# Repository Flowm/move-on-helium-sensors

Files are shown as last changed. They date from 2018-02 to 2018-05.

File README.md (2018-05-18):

# MOVE-ON Helium Sensors
Sensors subsystem for the MOVE-ON Helium high-altitude balloon mission.

A detailed system description can be found in the system documentation.

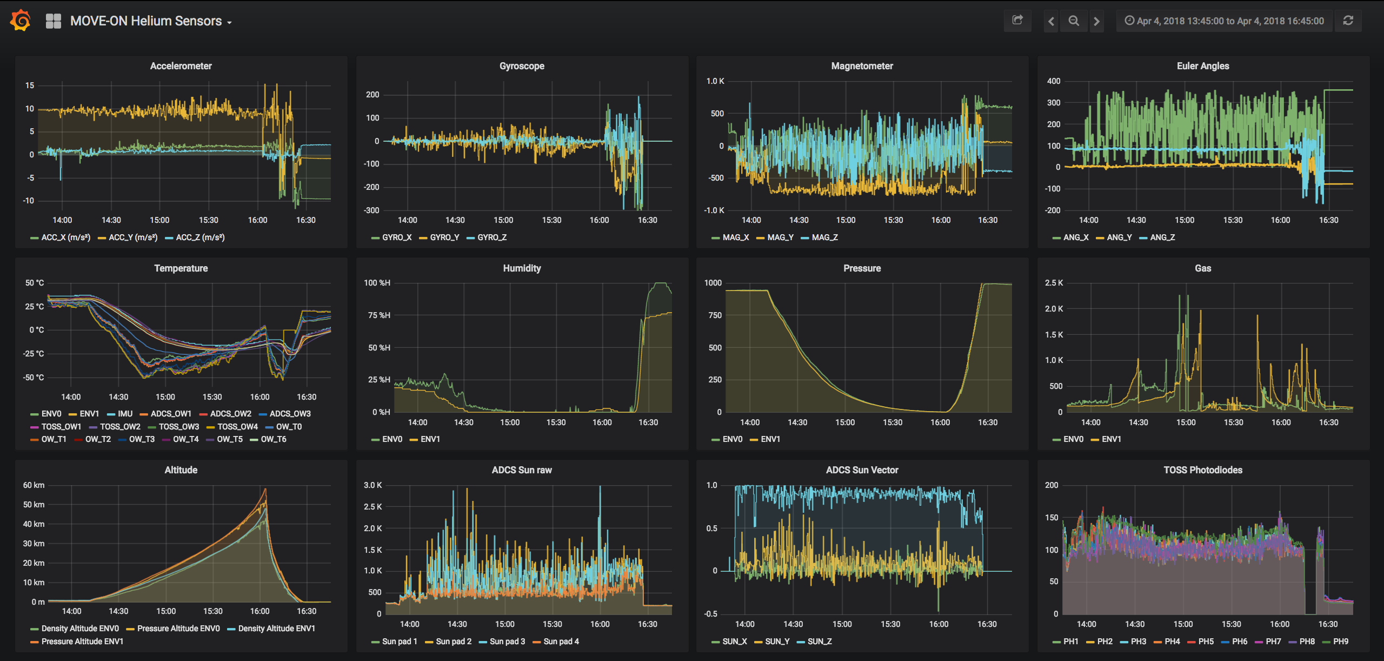
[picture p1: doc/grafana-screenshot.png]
Grafana dashboard


## Interfaces
### Micro USB
The output from Micro USB can be read with the following command (MacOS):
```
picocom -b 115200 /dev/tty.usbmodem1453
```
(`usbmodem1453` needs to be adjusted on your system)

## Setup
### Requirements
- GNU Arm Embedded Toolchain
- mbed-cli
- stlink

### MacOS
```
brew cask install gcc-arm-embedded
brew install stlink openocd direnv
sudo easy_install pip
pip install virtualenv

echo 'eval "$(direnv hook bash)"' >> ~/.bashrc
echo 'eval "$(direnv hook zsh)"' >> ~/.zshrc
```

If `pip install` does not work try it with the parameter `--user python`.

### Linux
```
sudo apt install gcc-arm-none-eabi openocd
sudo apt install python-pip python-dev build-essential direnv
pip install virtualenv

echo 'eval "$(direnv hook bash)"' >> ~/.bashrc
echo 'eval "$(direnv hook zsh)"' >> ~/.zshrc
```

### Mbed-cli
New shell in project directory:
```
direnv allow
pip install mbed-cli
```

## Development
### Compile
In `src` dir:
```
make
```

### Developing in SW4STM32 (Eclipse)
1. `mbed-cli export -i sw4stm32 --profile config/develop.json`
2. `File` -> `Open Projects from File System` (In Eclipse)
3. Choose the `move-on-helium-sensors` project.
4. Remember to regenerate the project files everytime you add a new library with `mbed-cli add ...`.

## Reference
### Build targets
From the `src` directory:

| Command | Description |
| --- | --- |
| make build (default) | Generate toplevel makefile and build project sources |
| make clean | Remove build artifacts and toplevel makefile |
| make flash | Upload firmware to locally attached uC with st-flash |
| make rflash | Upload firmware to uC attached to remote ci host |
| make rtail | Tail serial output from uC attached to remote ci host |
| make deploy | Combines rflash and rtail |

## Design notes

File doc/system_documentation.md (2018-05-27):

# MOVE-ON Helium Sensors System Documentation

This report documents the sensors subsystem of the MOVE-ON Helium mission.

Members of the Sensor team are:

* Florian Mauracher (<florian.mauracher@tum.de>)
* Tejas Kale (<tejas.kale@tum.de>)
* Alexander Lill (<alexander.lill@tum.de>)

## Resources & TL;DR

* [Repository](https://gitlab.lrz.de/move-on/move-on_helium_sensors)
* [System Architecture](https://gitlab.lrz.de/move-on/move-on_helium_sensors/blob/master/doc/system-architecture.png)
* [Nucleo Firmware](https://gitlab.lrz.de/move-on/move-on_helium_sensors/tree/master/src)
* [Hardware Schematics](https://gitlab.lrz.de/move-on/move-on_helium_sensors/tree/master/hardware)
* [Live data visualization](https://move.frcy.org)

## Mission Overview (MOVEON-GENERAL)

The MOVE-ON project aims to develop and start a high altitude pseudo satellite (HAPS) on board of a high-altitude (stratospheric) balloon every half year. This serves as a platform for short-lived and cost-efficient experiments to verify and test spacecraft technologies.

The expected mission duration for a high altitude balloon flight is 4 to 6 hours during which the balloon reaches an altitude up to 35 km.

The project is carried out by students of the [WARR](https://www.warr.de/en) (Scientific Workgroup for Rocketry and Spaceflight - German: Wissenschaftliche Arbeitsgemeinschaft für Raketentechnik und Raumfahrt in cooperation with the [LRT](https://www.lrt.mw.tum.de) (Chair of Astronautics) of the Technical University of Munich.

Suitable scientific or technical payloads are developed by students, employees of the LRT or provided by external partners and are the main driver for the technical requirements of every balloon mission.

MOVE-ON leverages existing knowledge from previous satellite missions of the chair and prepares the team as well as new technologies for upcoming satellite generations.

### Strategic Mission Goals (MOVEON-GENERAL)

MOVE-ON is the follow-up mission of the [MOVE-II](https://www.move2space.de/MOVE-II) miniature satellite (CubeSat) that was developed by the LRT together with students of the WARR.

The MOVE-ON missions are intended as a transitional project until the next satellite mission and aim to pass existing knowledge of the development of small satellites to a new generation of students and deepen their understanding of related technologies.

Besides distributing in-depth technical knowledge it also focuses on the upkeep and improvement of established processes and tools in regards to hardware and software.
Leveraging the relatively short and repeated development cycles (in comparison to small satellites) it additionally aims to create an adapted strategy for the agile development of embedded systems on small satellites.

### Technical Goals (MOVEON-GENERAL)

Existing technologies of previous and current satellite missions are intended to be used, extended and tested whenever possible.
Additionally, the continuous in-house development of the central subsystems for small satellites improves the capabilities of the LRT and the WARR in the development, manufacturing and qualification of satellite technology.
New strategies for the design and development of embedded systems can be tested rapidly with minimal cost and small associated risks.

## MOVE-ON Helium System Overview (MOVEON-HE-GENERAL)

The MOVE-ON Helium mission consists of a balloon, connecting strings and a gondola with a payload mounted on top of the gondola. The gondola is a PVC box and consists of all the mission-critical components including power, communication and health monitoring systems. The box serves to insulate the electronics from the extremely cold temperatures in the stratosphere.

The system is split into several key subsystems. Such a modular architecture allows for a structured development approach where each subsystem is developed and tested independently.



 The MOVE-ON Helium balloon has the following subsystems interconnected as shown in the figure above:

Command and Data Handling (CDH)
:   The CDH subsystem is the brain of the gondola. It controls all the other subsystems via various interfaces. CDH controls the power to the various systems and can switch off noncritical systems when the batteries run low or a subsystem is malfunctioning. Data from the sensors system is used for monitoring the health of the gondola and also its GPS position. CDH downlinks this telemetry data via the COM subsystem to the ground station.

Sensors (SEN)
:    The sensors subsystem provides environmental data and system health information for monitoring and tracking the balloon. It houses various sensors including a GPS module which provides the real-time position of the balloon.

Electrical Power System (EPS)
:   EPS houses the batteries, solar cells and the voltage converters. It is responsible for providing power to all the other subsystems. The EPS is designed in a modular way such that multiple such systems can be plugged in to scale to the needs of the mission. [ref: Thomas Grübler (12.2017) "Highly Integrated Smart Satellite Panels for Commercial Space Applications"]

Communications (COM)
:   The COM system consists of an RF link and is responsible for sending telemetry data from the balloon to the ground station.

Camera (CAM)
:   The camera system houses a GoPro capturing cool photos from the edge of space.

Payload (PL)
:   Payload is the scientific payload that is the main purpose of this balloon mission. It is mounted on top of the gondola and sends its data to CDH for transmission to the ground station.

Over the past 2 months, we have worked on developing the Sensors subsystem, starting from selecting commercially available components to integrating all of them on a single PCB. This subsystem is described in detail in the next section.

## System Description

The main responsibility of the sensors subsystem is to collect data from all connected sensors and provide this data to the CDH subsystem upon request. Simultaneously the collected data is stored locally at a higher data rate for later analysis.

Key components of the sensors subsystem

The sensors subsystem consists of the following key components:
<!--The figure below shows the key components of the subsystem and the connections between them.-->

* Internal Board
  * Microcontroller (NUCLEO-L432KC)
  * Storage Module (Adafruit OpenLog)
  * GPS module (uBLOX MAX-M8C Pico)
  * Motion sensor (BNO055)
* External Boards
  * Environmental sensor (BME680)
  * Sun Sensor (MOVE-II ADCS Sidepanel)
  * Sun Sensor (TOSS Photodiode board)
* Distributed on Gondola
  * 4x Temperature sensors (DS18B20)

The internal board is a self-developed PCB which is mounted on the inside of the gondola. The external boards were mounted as described in the Structure chapter. They are connected over SPI to the microcontroller. Multiple temperature sensors are placed near critical components of the gondola and also on the outside of the gondola.

During testing, it was found that the GPS does not work when wrapped with MLI. Due to this, the GPS module was mounted on a side wall with its antenna sticking out of the MLI insulation.
<!--
Each component is connected to the microcontroller using one of the  following communication buses, depending on what the sensor supports:
* UART
* I^2^C
* SPI
* OneWire-->

### Hardware

Since this is a proof of concept mission for the new sensors microcontroller, breakout boards are used for the majority of components. This enables fast prototyping and easy development.

For the initial verification of all components and connections the breakout boards were combined on a single breadboard as visible on the image below.


After successful verification, a PCB was designed integrating all internal breakout boards and providing dedicated connectors for each external component. The hardware schematics are available in the [repository](https://gitlab.lrz.de/move-on/move-on_helium_sensors/tree/master/hardware).



In the future all of the internal sensors could be integrated onto a single PCB which would significantly decrease the physical dimensions and weight of the board.

#### Microcontroller (NUCLEO-L432KC)

Our main computing module is a NUCLEO-L432KC development board with the following features:

* STMicroelectronics STM32L432KC microcontroller in 32-pin package
* ARM Cortex M4 architecture with FPU
* Adjustable CPU frequency from 2-80 Mhz
* 256 KB Flash and 64 KB SRAM
* Support for the ARM mbed OS Real-time operating system (RTOS)
* On-board ST-LINK/V2-1 debugger/programmer

The ARM Cortex-M4 based microcontroller was chosen due to its low base power consumption with reduced clock frequency while still offering sufficient processing power for higher level abstractions and possible future data processing.

### Software

#### Operating System

The MOVE-ON Sensor board is using the ARM Mbed OS real-time operating system. Mbed OS provides a convenient abstraction for the complexity of the underlying ARM Cortex-M4 microcontroller.

The RTOS functionality of Mbed OS with its priority based scheduling allows event-based actions with a guaranteed response rate and multiple concurrent threads with different priorities.

#### Data Acquisition

<!--
```https://www.planttext.com/
@startuml

class Sensors {
  -BNO055IMU imu;
  -BME680 env0;
  -BME680 env1;
  -Sidepanel adcs;
  -DS18B20 temperature;
  -GPS gps;
  -Storage storage;
  -CDHUart cdhuart;
  +void setup();
  +void loop();
  +void log();
}

class SensorThread {
  +void start()
  +void loop()
  +bool setup()
  +void update()
  +void set_update_rate(int)
  +void set_priority(priority)
  -Thread _thread
}

class BNO055IMU
class BME680
class Sidepanel
class DS18B20
class GPS

SensorThread <|-down- BNO055IMU: Inheritance
SensorThread <|-down- BME680: Inheritance
SensorThread <|-down- Sidepanel: Inheritance
SensorThread <|-down- DS18B20: Inheritance
SensorThread <|-down- GPS: Inheritance

Sensors "1" -right- "*" SensorThread: "      "

@enduml
```
-->

```mermaid
sequenceDiagram
    participant m as main
    participant s as Storage
    participant c as CDHUart
    participant thread as SensorThread
    participant l as OpenLog
    participant cdh as CDH

    m->>+s: new()
    m->>+c: new()
    m->>+thread: start()

    loop Every second
        thread->>thread: update()
        thread->>s: lock()
        thread->>s: store_data()
        thread->>s: unlock()
    end

    loop Every second
        m->>s: lock()
        m->>s: retrieve_data()
        s-->>m: data
        m->>s: unlock()
        m->>l: print()
    end

    opt sometimes
        cdh->>c: request_data()
        c->>s: lock()
        c->>s: retrieve_data()
        s-->>c: data
        c->>s: unlock()
        c->>cdh: data
    end

    thread-->>-m:terminate()
```

To gather the data from multiple different sensors, each sensor is implemented as a self-contained module in the form of a separate class with all its dependencies.
Each sensor module is running as a separate thread with a set refresh rate, relying on Mbed OS for scheduling between the threads.

Each sensor thread communicates with its respective sensor to initiate a measurement when required and gather the resulting data.The data is then stored in a shared data structure containing the latest measurements from each sensor. To ensure the data structure remains consistent at all times a mutex is used to lock the data structure immediately before storing the data and unlock it again right afterwards.

At the end of a measurement period each sensor thread sleeps for the remaining time until the desired data update rate is reached, providing sufficient time for all other sensor threads to be scheduled.

#### Sensor Update Frequency

| Sensor | Update Frequency(ms) |
| --- | ---: |
| GPS | 1000 |
| BME | 1000 |
| BNO055-IMU | 200 |
| SidePanel | 200 |
| TOSS | 500 |
| One Wire Temp | 2000 |

#### CDH Communication

CDH asks the sensors system for data every second over the UART link by sending a single command byte. The response is a mutually agreed upon data structure which contains the most recent sensor data. The content is verified with a CRC checksum to avoid data corruption.

As GPS data is critical for real-time balloon tracking and time synchronization, responding to CDH data requests is handled with a high priority event queue. When a new request for data comes in from CDH (a byte is received on the UART RX line), an interrupt is generated by the UART peripheral on the microcontroller. The interrupt handler simply reads the command and queues an event onto the event queue for processing. The event callback is then executed when the responsible thread gets scheduled the next time. The command processor then responds with the sensor data on the UART TX line.

#### Persistent Data Storage

A UART data logger module is used to log data locally on the sensors subsystem. This is required because:

* CDH cannot handle data at high frequency due to power budget constraints
* Different sensors produce different amounts of data at different rates
* In case of a CDH failure, we will still have a backup of the sensor data

This is implemented using the OpenLog module from [Sparkfun](https://www.sparkfun.com/products/13712). It is an Atmel Xmega 328p microcontroller which logs all data that it receives via UART to an SD card. The used SD card has a capacity of 32 GB and provides sufficient storage capacity for up to a month of continuous data storage ( `115200/8*60*60*24/1024/1024/1024` = 1.15 GB/day with 100% utilization of the UART line).

### Sensors

The following sensor modules are integrated into the sensors subsystem.

#### GPS Module (uBLOX MAX-M8C Pico)

The MAX-8 series of standard precision GNSS modules features the reliable performance of the u-blox 8 positioning engine, which receives GPS, GLONASS, QZSS and SBAS signals. The MAX-8 series delivers high sensitivity and minimal acquisition times in an ultra compact form factor. The MAX-8 series provides high sensitivity while featuring low power consumption. It also supports advanced Power Save Modes. It also provides message integrity protection, geofencing, spoofing detection, and odometer functionalities. The module also supports a high altitude mode which works up to 50 km in flight mode.

The module is connected to the microcontroller over a dedicated I^2^C bus. It provides GPS data in the standard NMEA format. This raw NMEA is parsed to extract the time and real-time GPS position. Since NMEA also consists of other useful data, it is also logged in raw form.

For configuration of the sensor module, the uBLOX supports a proprietary binary protocol. This protocol is currently neither used nor implemented, but instead configuration messages can be created using a software provided by uBLOX to generate these binary messages which can then be written to the module over I^2^C.

For the flight the GPS was configured with the following settings:

* Dynamic Model : Airborne 2g mode
* Min SV elevation : 0
* Fix Mode : 3D only

The software is configured to write the UBX CFG message to the GPS chip on startup. Further, the GPS module always transmits the last known location in case there is no GPS lock.

#### Motion Sensor (BNO055)

The Bosch Sensortec BNO055 motion sensor implements an intelligent 9-axis Absolute Orientation Sensor, which includes sensors and sensor fusion in a single package. This sensor integrates a triaxial 14-bit accelerometer, a triaxial 16-bit gyroscope with a maximum range of ±2000 degrees per second, a triaxial geomagnetic sensor and a 32-bit microcontroller running the company's BSX3.0 FusionLib software. The BNO055 is connected over a second I^2^C bus.

Attitude data from this sensor is used to measure the orientation of the gondola and also to test the effectiveness of a stabilization system developed by the structure team. This data is also used to mark the exact time when the balloon bursts and the gondola starts its free fall.

#### Environmental Sensor (BME680)

The Bosch Sensortec BME680 is described as an environmental sensor and provides, besides measurements of the temperature, humidity and pressure also an estimate of the current air quality in the form of a gas resistance measurement. The sensor provides an SPI interface for configuration and data retrieval.

Temperature and pressure data from this sensor is combined on the ground to provide an additional altitude calculation based on a simple [atmospheric density model](tools/grafana/bin/sensor-parser/moveon-sen-parser.cpp).

#### Sun Sensor (MOVE-II ADCS Sidepanel)

Sun angle sensors used in the MOVE-II CubeSat are commercial-off-the-shelf components, which are not extensively tested for space operation. The MOVE-ON mission provides an excellent platform for testing the performance of these sensors in a space-like environment. One of the side panels from the MOVE-II CubeSat is attached to the exterior of the gondola to record data from the sun sensor attached to it. This panel also has an IMU and various temperature sensors. Data from these is also recorded.

The Sidepanel is connected over the same SPI bus that connects all the external components of the sensor subsystem. It operates as a SPI slave and responds to data requests from the Nucleo microcontroller. The Sidepanel has the same software version as on the MOVE-II satellite.

#### Sun Sensor (SFH 2430)

A separate component with multiple photodiodes arranged in a spherical manner is being developed by students of the [*Practical Course on Astronautics*](https://www.lrt.mw.tum.de/index.php?id=172&L=1).

This experimental payload aims to provide a primitive sun sensor by combining the measurements of the photodiodes and some supplemental temperature sensors. An [Atmel AtMega32u4 breakout](https://www.dfrobot.com/product-1075.html) combines these measurements and provides a calculated sun vector as well as the raw data over a SPI interface to the Nucleo sensor board.

#### Temperature Sensors (DS18B20)

The DS18B20 digital thermometer provides 9-bit to 12-bit Celsius temperature measurements from -55°C to +125°C with a 0.5°C accuracy from -10°C to +85°C. This sensor communicates over a 1-Wire bus that by definition requires only one data line (and ground). In addition, the DS18B20 can derive power directly from the data line ("parasite power"), eliminating the need for an external power supply. The 1-Wire protocol required for interfacing with this sensor is implemented in software using an mbed library.

### Development Environment

While each team member has his own Nucleo board and the sensor he's currently working on, most sensors were only available twice during development. To allow regular testing of all components in a combined setup, we set up a continuous integration and deployment pipeline based on GitLab and the GitLab Runner.

After every commit the GitLab Runner starts the docker container with the mbed-cli development environment, compiles the project and gathers the resulting firmware as an artifact. The next stage of the pipeline then uses this firmware image to flash the Nucleo microcontroller with all sensors attached which is connected to a Raspberry PI reachable from the build server. Additionally, debug output is captured over the USB serial port and logged in the build log.

### Data Visualization

In testing configuration, the Raspberry Pi logs data on the USB debug line of the Nucleo board, which is used by the OpenLog in the flight configuration. This data is then parsed by a Python script, published over the messaging protocol MQTT and stored as time series in an InfluxDB database. The Grafana web frontend provides an interactive visualization of the stored data.

Grafana screenshot

InfluxDB supports multiple data sources and can easily be extended to accept data received over the COM link for live telemetry and tracking in flight.

### Power

Currently the sensors subsystem with all sensors connected consumes an average of 326 mW. Although there are no hard power requirements for the power budget of the sensors system energy consumption was kept in mind throughout the component selection and development process.

Nevertheless there are certain components that require significant amounts of energy impacting the total energy consumption:

|Component | Consumption | Disclaimer |
|- | - | - |
|uBlox GPS | <74 mW | During GPS acquisition|
| OpenLog | <70 mW | When writing to SD card flash |
|MOVE-II ADCS Sidepanel | ~60 mW | Separate XMega uC |
|TOSS Photodiode | ~50 mW  | Separate AVR uC |
|Microcontroller + Sensors | *~72mW* | *Approximate value, naively calculated* | <!-- 326-74-70-60-50 -->
|**Sum** | **326 mW** | |

## Flight

The sensors microcontroller gathered data continuously for the entire duration of the flight. It did not reset even at the low temperatures experienced during the transition through the upper parts of the troposphere. However not all sensors functioned correctly for the entire duration of the flight:

* GPS could not acquire a lock during most of the flight. This was most likely caused due to its close proximity to the MLI wrapping.
* The FAT32 filesystem on the SD card was corrupted sometime during the final integration. Due to this, no data was recorded on the OpenLog SD card during the flight.

### Flight Data

Flight data was recovered from the CDH SD card after the gondola was recovered. This data is presented below.

#### System Status

#### Temperature

The one wire temperature sensors were positioned on the gondola as follows:

| SENSOR | POSITION|
| --- | --- |
|OW0 |EPS Board|
|OW1 |U1 (Sensors Board)|
|OW2 |U3 (Sensors Board)|
|OW3 |Palyoad|
|OW4 |GoPro|
|OW5 |Battery Pack|
|OW6 |U2 (Sensors Board)|

Along with the 7 one wire temperature sensors of the sensors subsystem, the following other temperature sensors from other components were available:

* 3 One wire temperature sensors on the ADCS Sidepanel
* 4 One wire temperature sensors on the TOSS sunsensor board
* One temperature sensor integrated into each BME680 chip
* One temperature sensor on the BMX055 IMU.

The following graph presents the temperature profile of the flight as seen by the various sensors. A clear gap is seen in the internal and the external temperatures.

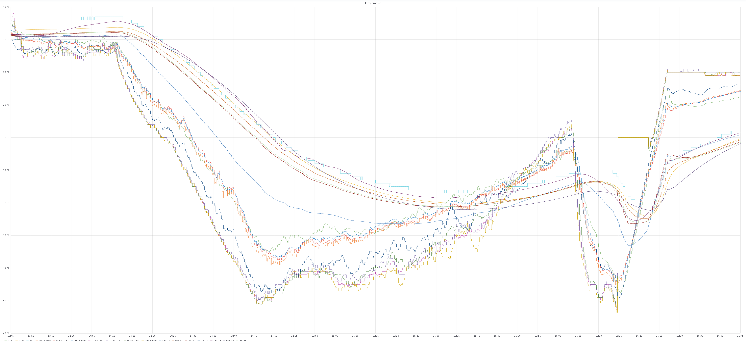
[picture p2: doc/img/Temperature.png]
Temperature profile


#### Pressure and Altitude

The following graph shows the pressure as recorded by the two BME680 sensors. The ENV0 sensor was placed outside while the ENV1 sensor was inside the gondola.

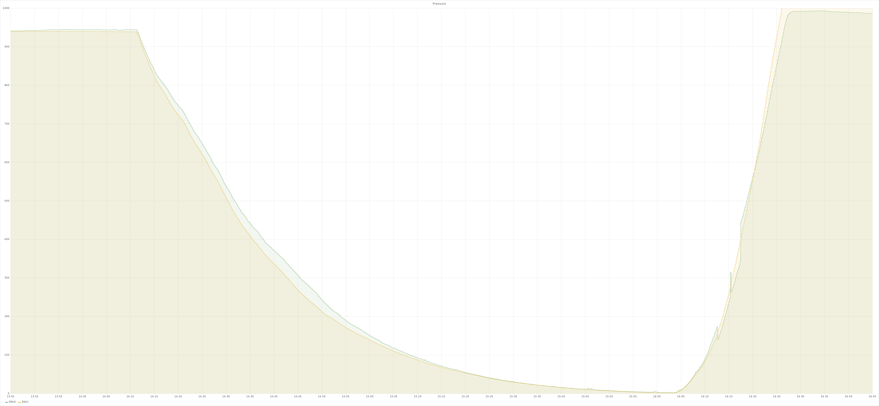
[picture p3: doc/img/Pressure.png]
Pressure profile


Altitude was calculated using two different methods:

1. [Pressure Altitude](https://en.wikipedia.org/wiki/Pressure_altitude) is calculated using only the pressure.
2. [Density Altitude](https://en.wikipedia.org/wiki/Density_altitude) is the Pressure altitude adjusted for temperature.

The following graph shows the altitude of the flight:
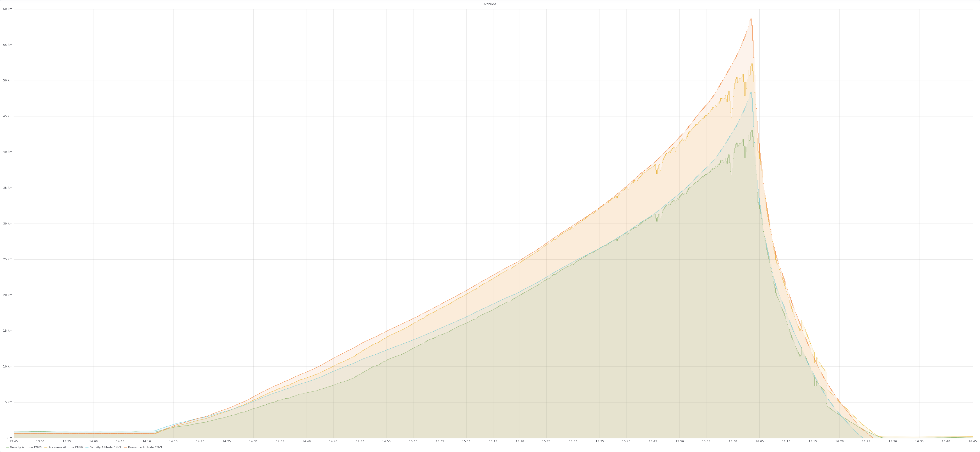
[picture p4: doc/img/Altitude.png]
Altitude profile


#### Motion Data

The BNO055 IMU recorded the gondola rotational speed, acceleration due to gravity, magnetic field data and the euler angles calculated onboard the sensor.

The following graphs show the gyroscope, Accelerometer and magnetometer data over the flight duration.

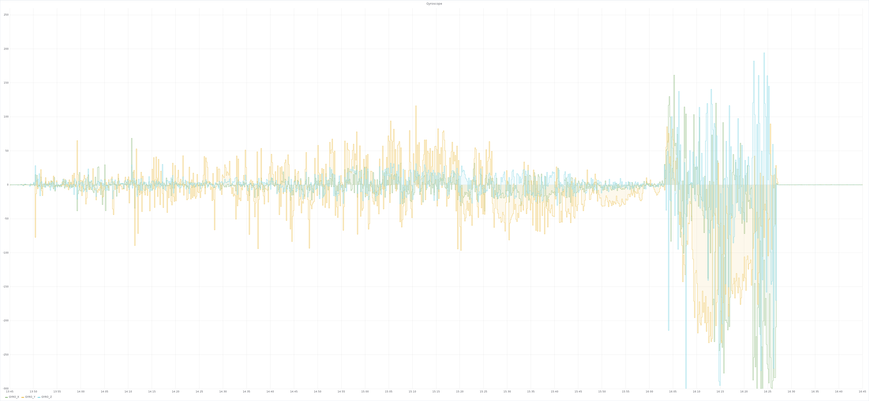
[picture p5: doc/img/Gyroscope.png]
Gyroscope profile

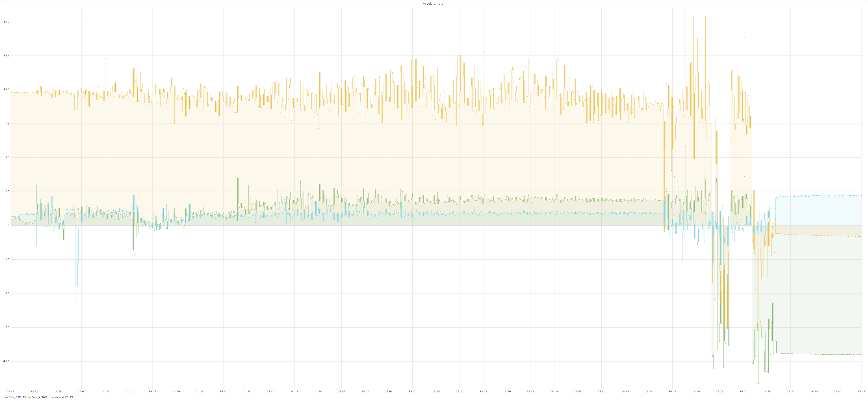
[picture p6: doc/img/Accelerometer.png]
Accelerometer profile

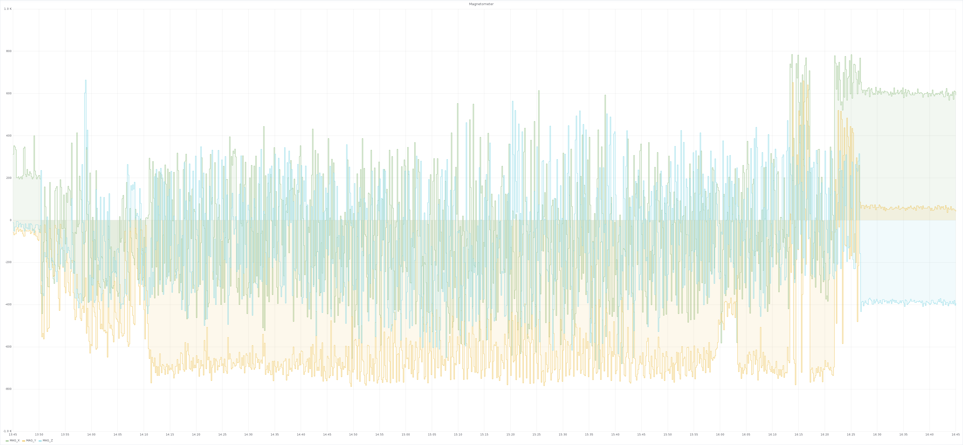
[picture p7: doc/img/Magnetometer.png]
Magnetometer profile


#### ADCS Sidepanel Data

The raw pad data from the ADCS sidepanel is shown below. The pads didnot exceed the ADC threshold of the sidepanel microcontroller.

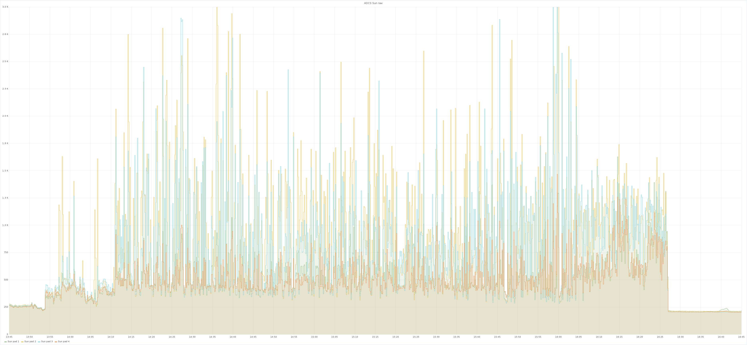
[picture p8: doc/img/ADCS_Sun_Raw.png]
Sun Raw profile


## References

### Sensor Modules

* [Components List](https://docs.google.com/spreadsheets/d/1G8NeRl4uM_pISfbMc-lu1pe1I8vzOqsSfUeEpfeaWEo/edit#gid=0)
* [GPS Ublox Max M8](https://store.uputronics.com/index.php?route=product/product&path=60_64&product_id=72)
* [BNO055 IMU](https://www.adafruit.com/product/2472)
* [BME680 Enviornment](http://www.watterott.com/en/BME680-Breakout)
* [DS18B20 Temperature](https://datasheets.maximintegrated.com/en/ds/DS18B20.pdf)
* [MOVE-II ADCS SidePanel](https://redmine.move2space.de/projects/move2/wiki/Sidepanel_401)
* [Open Log Datalogger](https://www.sparkfun.com/products/13712)

### Source Code

* [MOVE-ON Helium Sensors](https://gitlab.lrz.de/move-on/move-on_helium_sensors/)
* [MOVE-II ADCS](https://gitlab.lrz.de/move-ii/adcs_software)
* [TOSS Sunsensor](https://gitlab.lrz.de/racoon-projects/thermal-sun-sensor)

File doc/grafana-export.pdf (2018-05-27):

# MOVE-ON Helium Sensors

Postflight analysis of the data stored on the CDH SD card

## Wed Apr 4 11:45:00 UTC 2018

to

## Wed Apr 4 14:45:00 UTC 2018

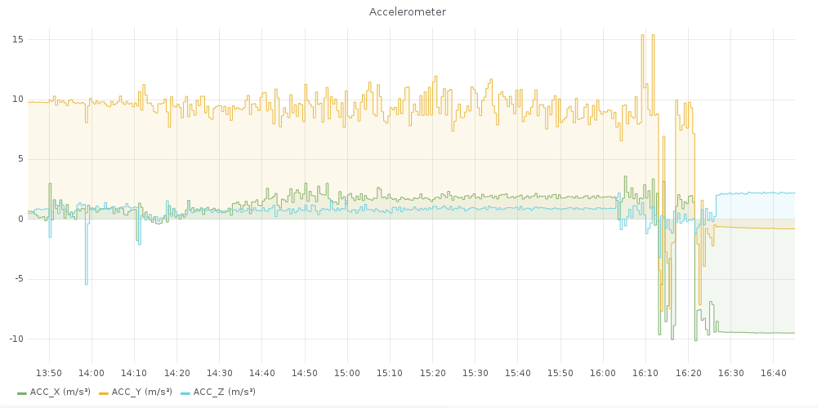
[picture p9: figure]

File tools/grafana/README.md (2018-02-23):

# Grafana visualization of moveon data

## Setup

### Components
- [Mosquitto](https://github.com/eclipse/mosquitto)
- [InfluxDB](https://github.com/influxdata/influxdb)
- [Telegraf](https://github.com/influxdata/telegraf)
- [Grafana](https://github.com/grafana/grafana)
- [Nginx](https://github.com/nginx/nginx)

### Install
- Automated setup of required software using [piot-ansible](https://github.com/Flowm/piot-ansible):
```
ansible-playbook -i "devpi," devpi.yml
```

- Clone the move-on_helium repository to `/opt/move-on_helium`
```
sudo mkdir -p /opt/move-on_helium
sudo chown deploy: /opt/move-on_helium
git clone --recurse-submodules git@gitlab.lrz.de:move-on/move-on_helium.git /opt/move-on_helium
```

- Install services and config
```
sudo /opt/move-on_helium/SEN/tools/grafana/setup.sh
```

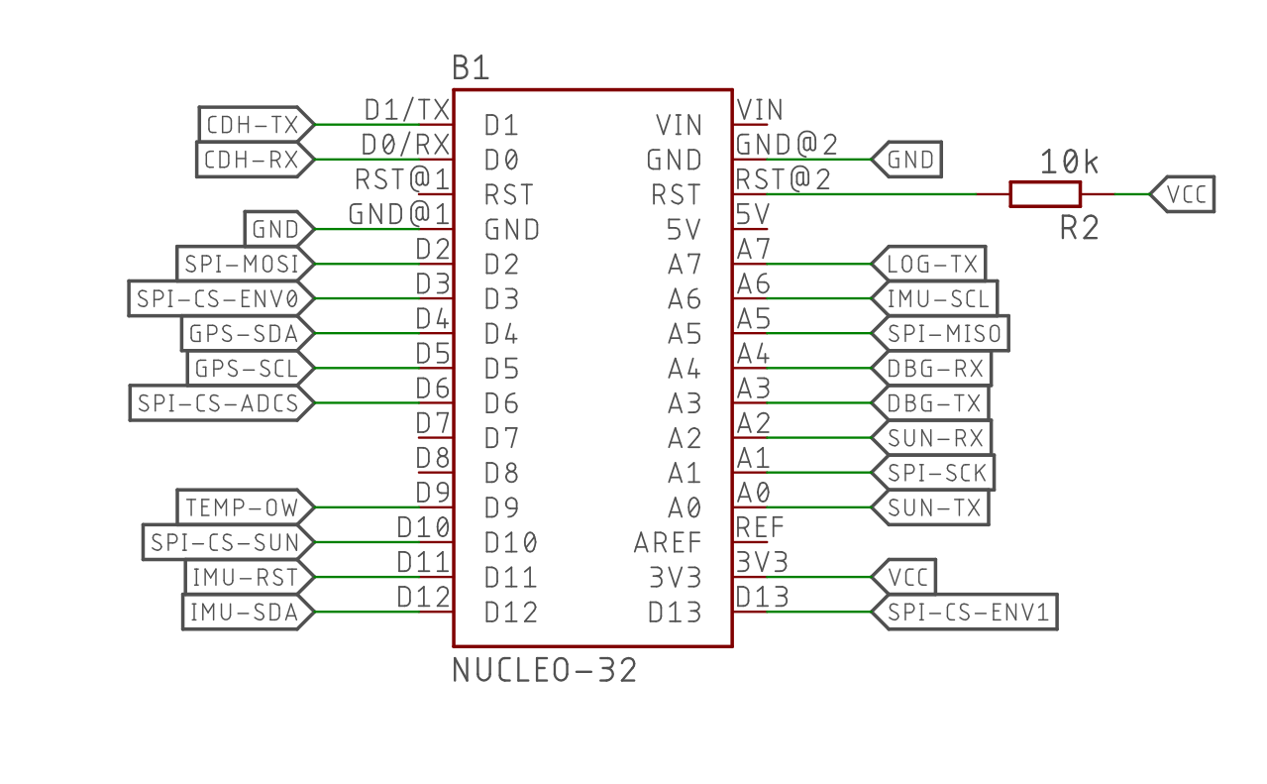
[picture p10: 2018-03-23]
doc/pinout.png

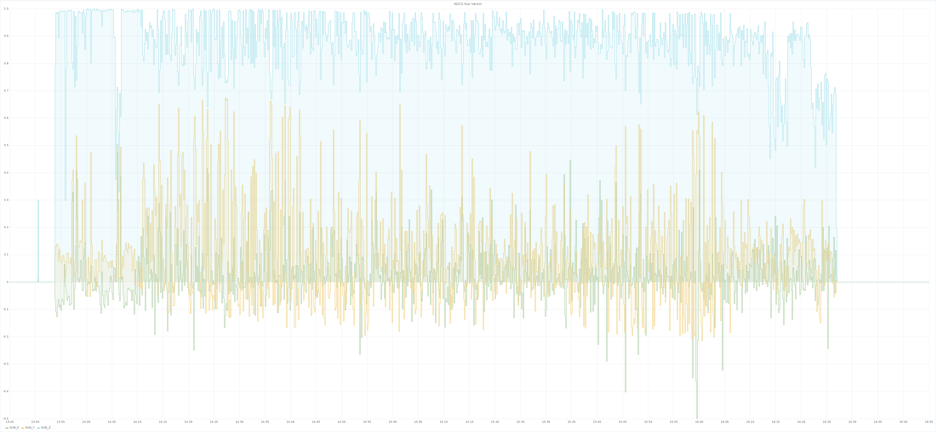
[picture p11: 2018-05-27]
doc/img/ADCS_Sun_Vector.png

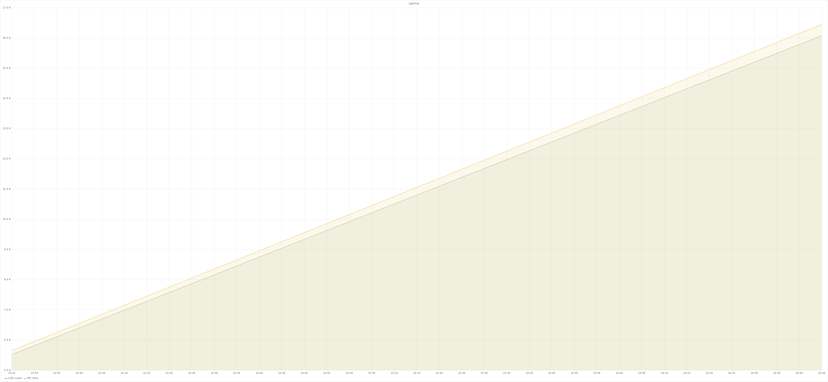
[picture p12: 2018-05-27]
doc/img/Uptime.png

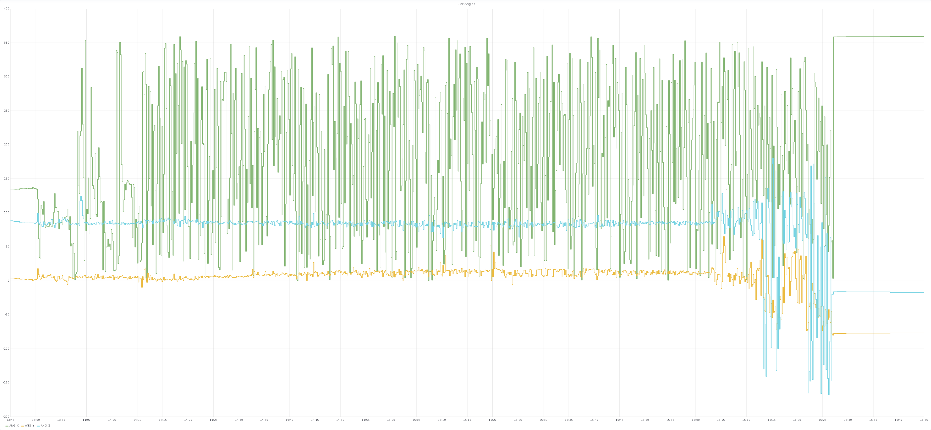
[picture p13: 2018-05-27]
doc/img/Euler_Angles.png

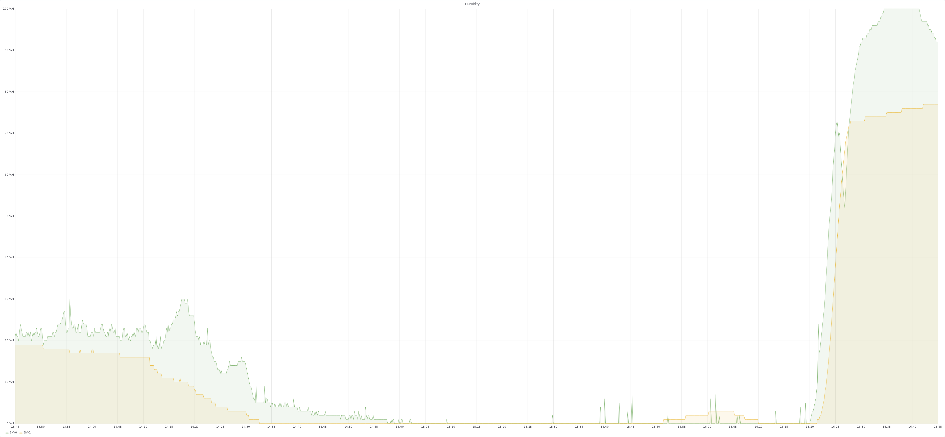
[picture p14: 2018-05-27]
doc/img/Humidity.png

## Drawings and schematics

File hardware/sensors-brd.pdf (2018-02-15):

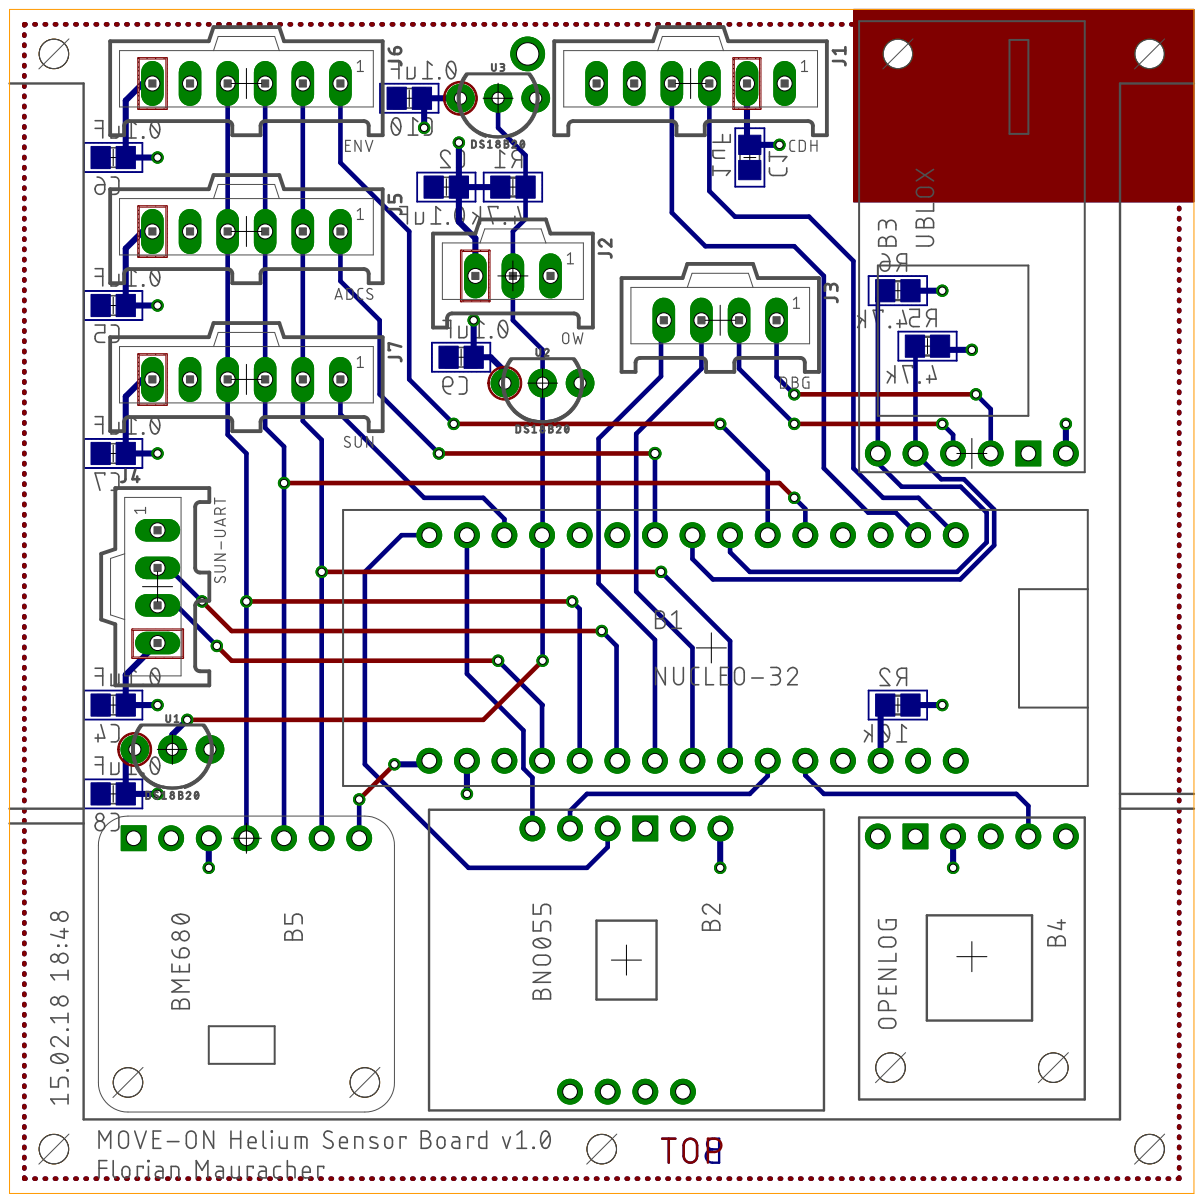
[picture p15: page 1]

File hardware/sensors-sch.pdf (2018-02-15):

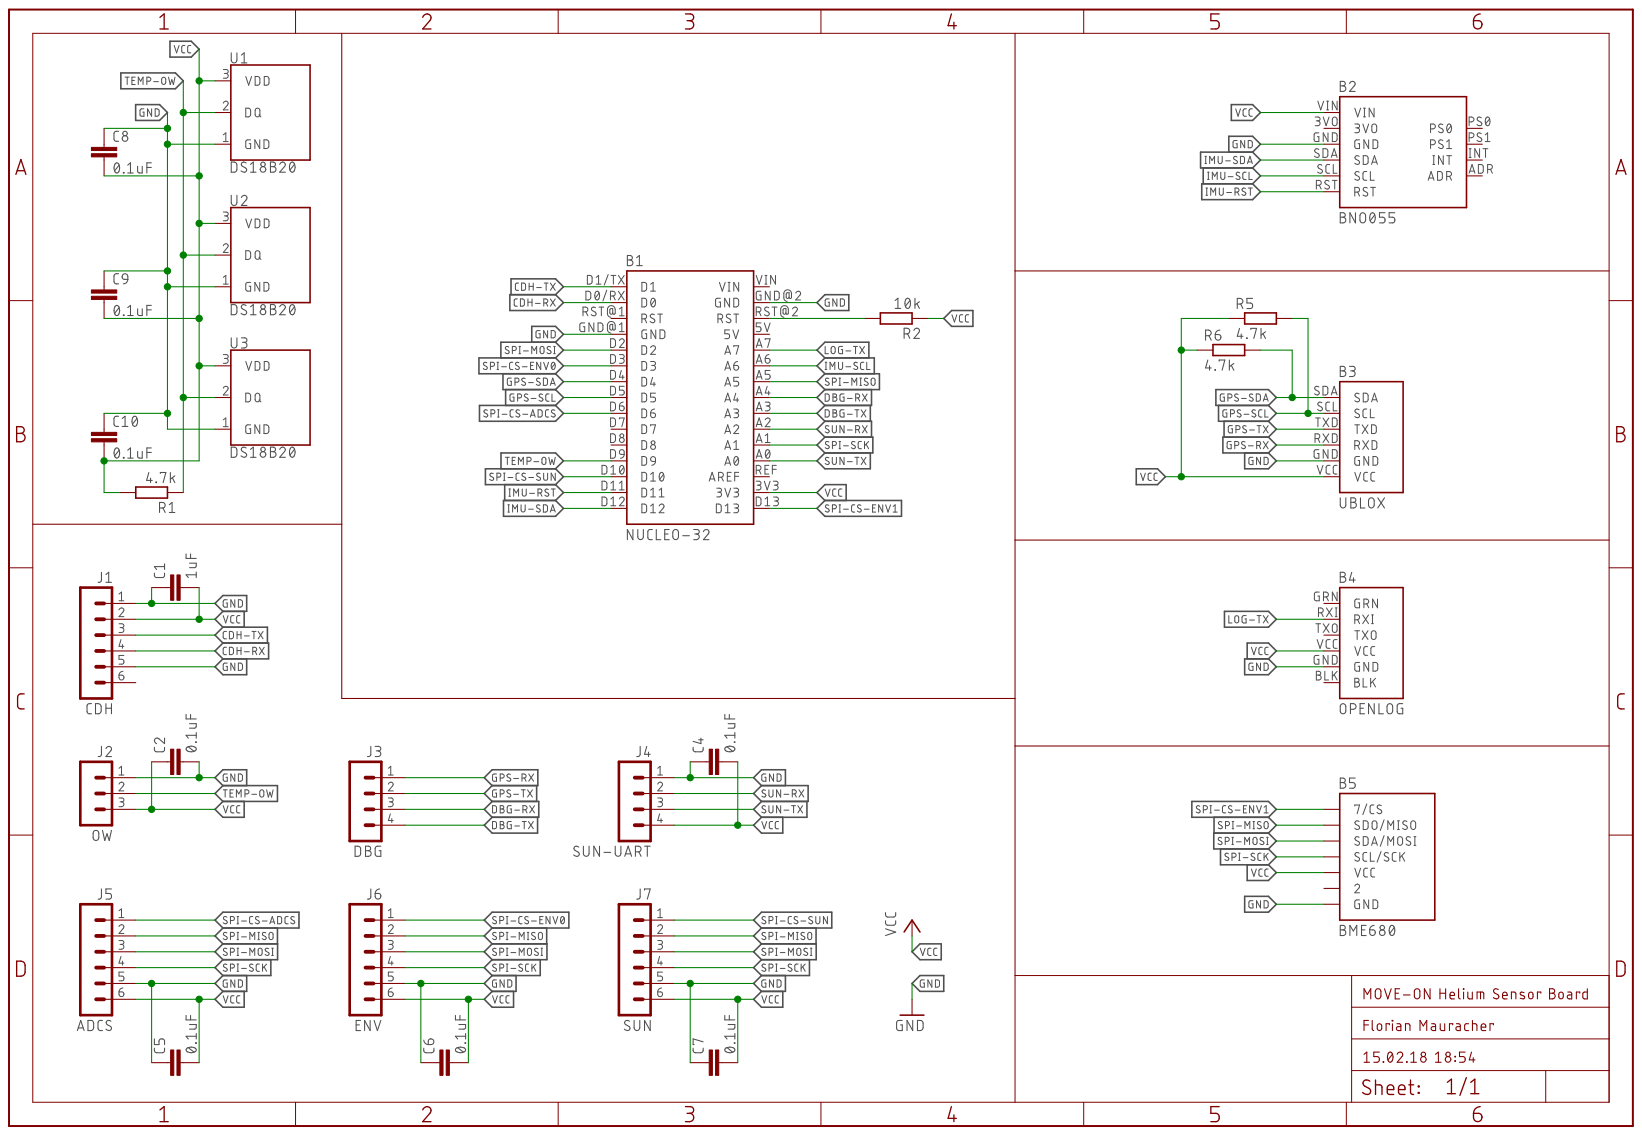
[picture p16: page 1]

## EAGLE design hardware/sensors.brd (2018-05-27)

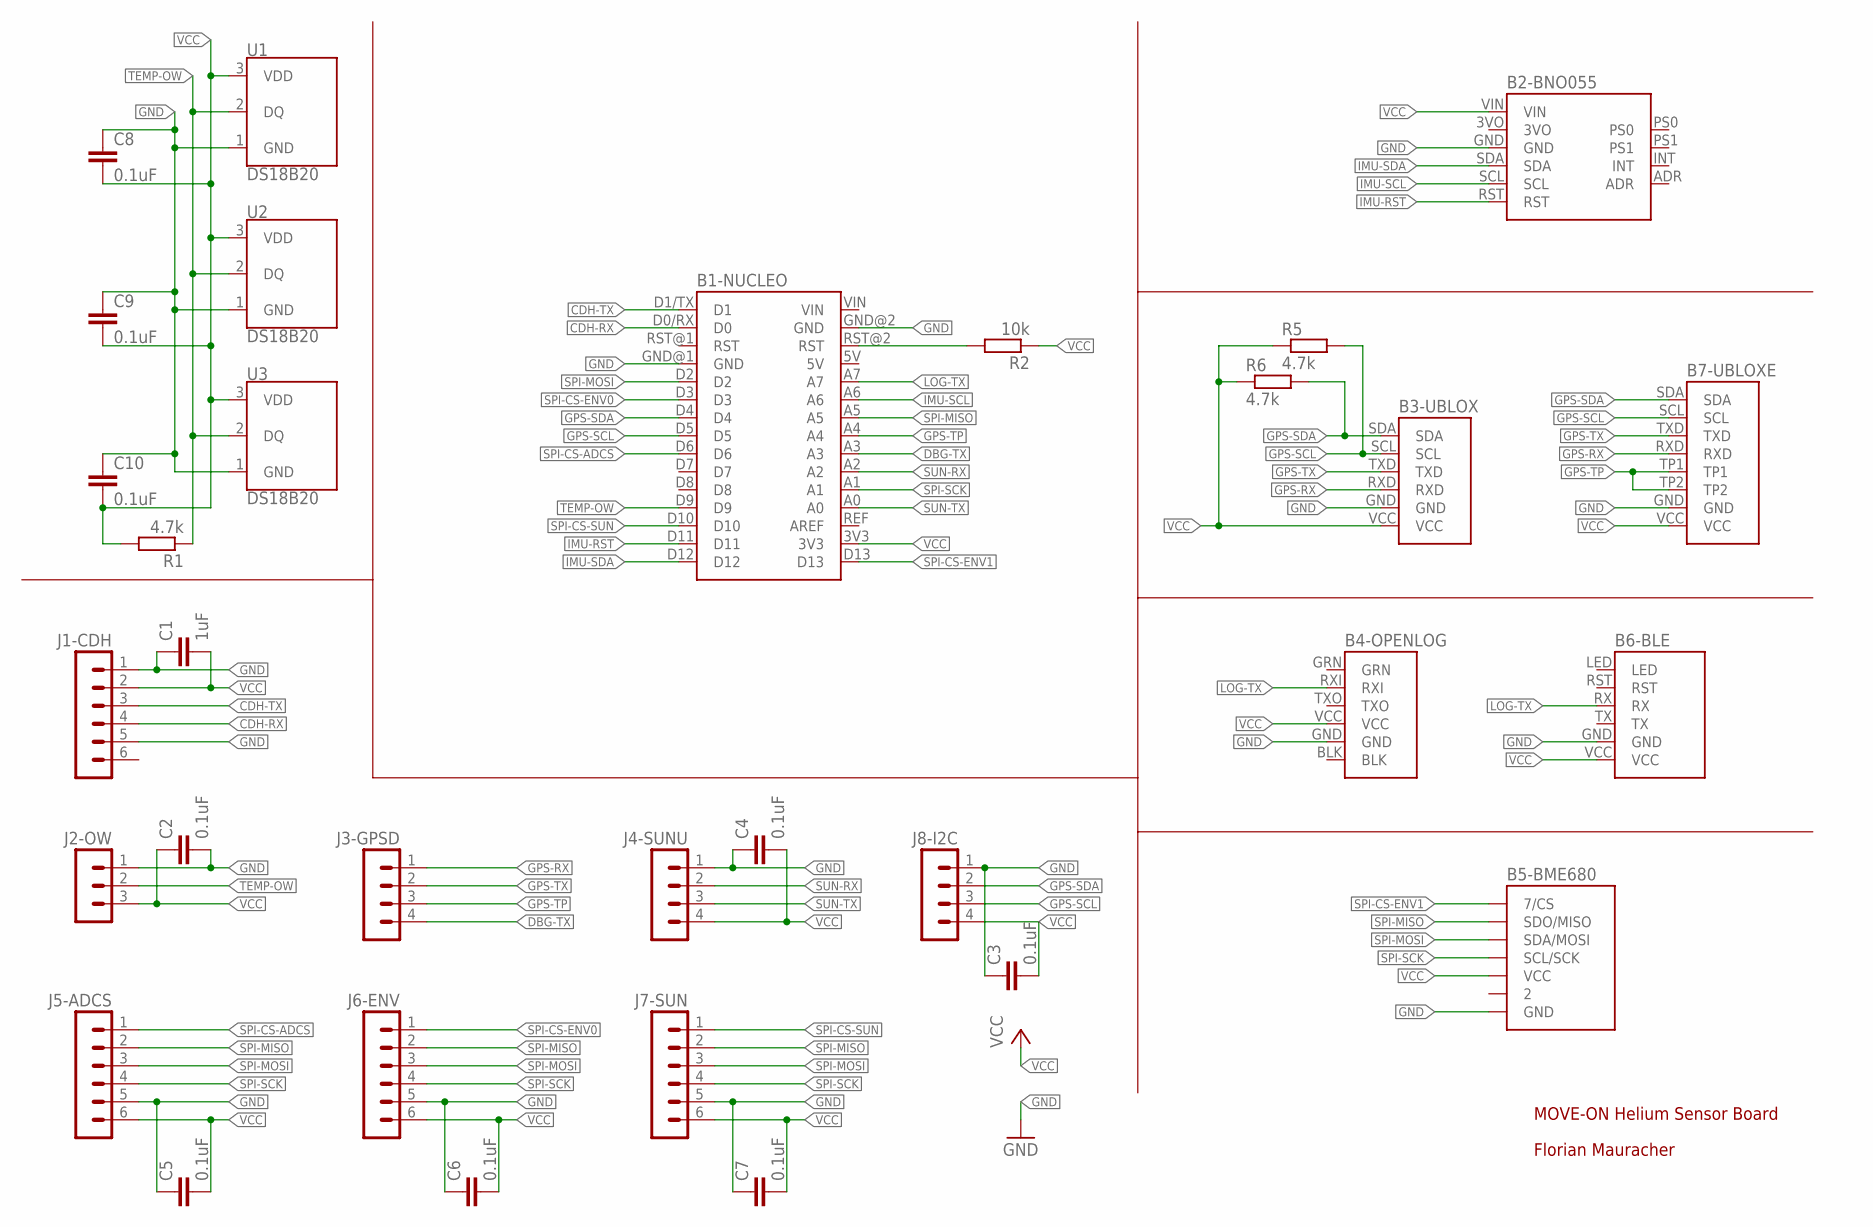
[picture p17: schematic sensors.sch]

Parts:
B1-NUCLEO: NUCLEO-32BO; NUCLEO-32
B2-BNO055: BOSCH-BNO055BO; BOSCH-BNO055
B3-UBLOX: UPUTRONICS-UBLOX-PICOBO; UPUTRONICS-UBLOX-PICO
B4-OPENLOG: SPARKFUN-OPENLOGBO; SPARKFUN-OPENLOG
B5-BME680: WATTEROT-BME680BO; WATTEROT-BME680
B6-BLE: HUAMAO-HM-11BO; HUAMAO-HM-11
B7-UBLOXE: UPUTRONICS-UBLOX-M8Q
C1: 1uF; C2012
C2, C3, C4, C5, C6, C7, C8, C9, C10: 0.1uF; C2012
J1-CDH, J5-ADCS, J6-ENV, J7-SUN: 90136-106; 90136-1?06
J2-OW: 90136-103; 90136-1?03
J3-GPSD, J4-SUNU, J8-I2C: 90136-104; 90136-1?04
R1, R5, R6: 4.7k; R2012
R2: 10k; R2012
U1, U2, U3: DS18B20; TO-92-AMMO

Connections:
5V: B1-NUCLEO.5V
CDH-RX: B1-NUCLEO.D0/RX (D0), J1-CDH.4
CDH-TX: B1-NUCLEO.D1/TX (D1), J1-CDH.3
DBG-TX: B1-NUCLEO.A3, J3-GPSD.4
GND: B1-NUCLEO.GND@1 (GND), B1-NUCLEO.GND@2 (GND), B2-BNO055.GND, B3-UBLOX.GND, B4-OPENLOG.GND, B5-BME680.GND, B6-BLE.GND, B7-UBLOXE.GND, C1.1, C2.2, C3.1, C4.1, C5.1, C6.1, C7.1, C8.1, C9.1, C10.1, J1-CDH.1, J1-CDH.5, J2-OW.1, J4-SUNU.1, J5-ADCS.5, J6-ENV.5, J7-SUN.5, J8-I2C.1, U1.1 (GND), U2.1 (GND), U3.1 (GND)
GPS-RX: B3-UBLOX.RXD, B7-UBLOXE.RXD, J3-GPSD.1
GPS-SCL: B1-NUCLEO.D5, B3-UBLOX.SCL, B7-UBLOXE.SCL, J8-I2C.3, R5.2
GPS-SDA: B1-NUCLEO.D4, B3-UBLOX.SDA, B7-UBLOXE.SDA, J8-I2C.2, R6.2
GPS-TP: B1-NUCLEO.A4, B7-UBLOXE.TP1, B7-UBLOXE.TP2, J3-GPSD.3
GPS-TX: B3-UBLOX.TXD, B7-UBLOXE.TXD, J3-GPSD.2
GRN: B4-OPENLOG.GRN
IMU-RST: B1-NUCLEO.D11, B2-BNO055.RST
IMU-SCL: B1-NUCLEO.A6, B2-BNO055.SCL
IMU-SDA: B1-NUCLEO.D12, B2-BNO055.SDA
LOG-TX: B1-NUCLEO.A7, B4-OPENLOG.RXI, B6-BLE.RX
NUC-RST: B1-NUCLEO.RST@2 (RST), R2.2
SPI-CS-ADCS: B1-NUCLEO.D6, J5-ADCS.1
SPI-CS-ENV0: B1-NUCLEO.D3, J6-ENV.1
SPI-CS-ENV1: B1-NUCLEO.D13, B5-BME680.CS (7/CS)
SPI-CS-SUN: B1-NUCLEO.D10, J7-SUN.1
SPI-MISO: B1-NUCLEO.A5, B5-BME680.SDO/MISO, J5-ADCS.2, J6-ENV.2, J7-SUN.2
SPI-MOSI: B1-NUCLEO.D2, B5-BME680.SDA/MOSI, J5-ADCS.3, J6-ENV.3, J7-SUN.3
SPI-SCK: B1-NUCLEO.A1, B5-BME680.SCL/SCK, J5-ADCS.4, J6-ENV.4, J7-SUN.4
SUN-RX: B1-NUCLEO.A2, J4-SUNU.2
SUN-TX: B1-NUCLEO.A0, J4-SUNU.3
TEMP-OW: B1-NUCLEO.D9, J2-OW.2, R1.1, U1.2 (DQ), U2.2 (DQ), U3.2 (DQ)
VCC: B1-NUCLEO.3V3, B2-BNO055.VIN, B3-UBLOX.VCC, B4-OPENLOG.VCC, B5-BME680.VCC, B6-BLE.VCC, B7-UBLOXE.VCC, C1.2, C2.1, C3.2, C4.2, C5.2, C6.2, C7.2, C8.2, C9.2, C10.2, J1-CDH.2, J2-OW.3, J4-SUNU.4, J5-ADCS.6, J6-ENV.6, J7-SUN.6, J8-I2C.4, R1.2, R2.1, R5.1, R6.1, U1.3 (VDD), U2.3 (VDD), U3.3 (VDD)
VIN: B1-NUCLEO.VIN

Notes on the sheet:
MOVE-ON Helium Sensor Board
Florian Mauracher

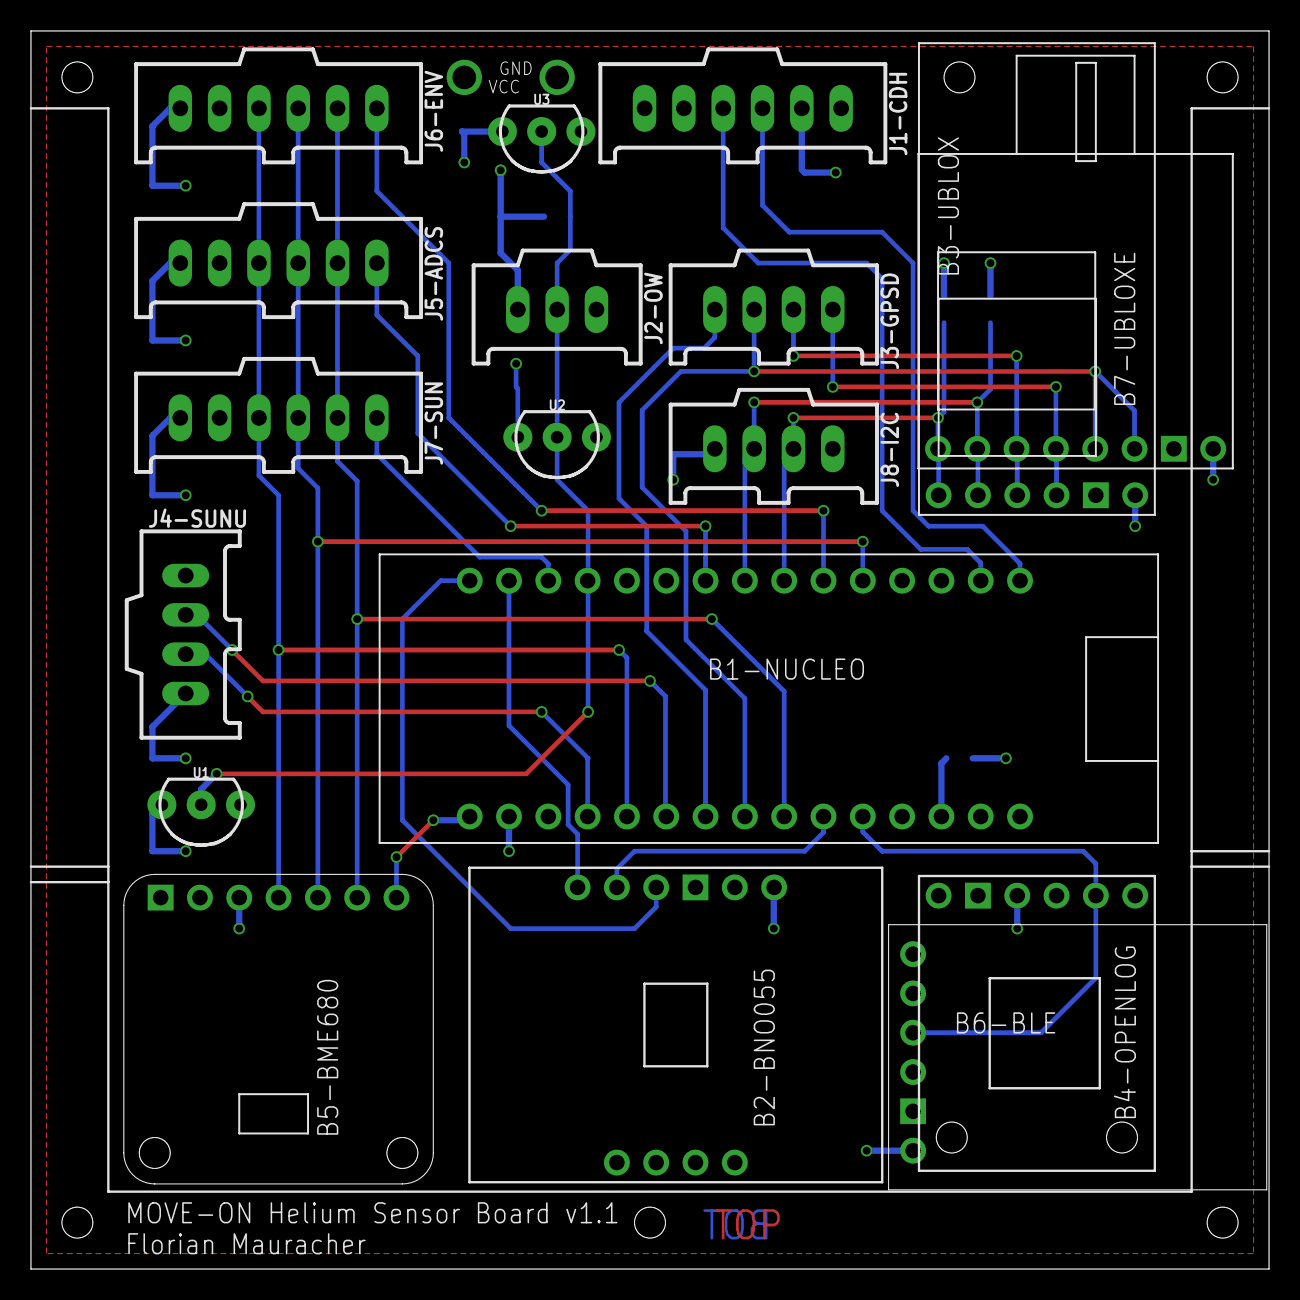
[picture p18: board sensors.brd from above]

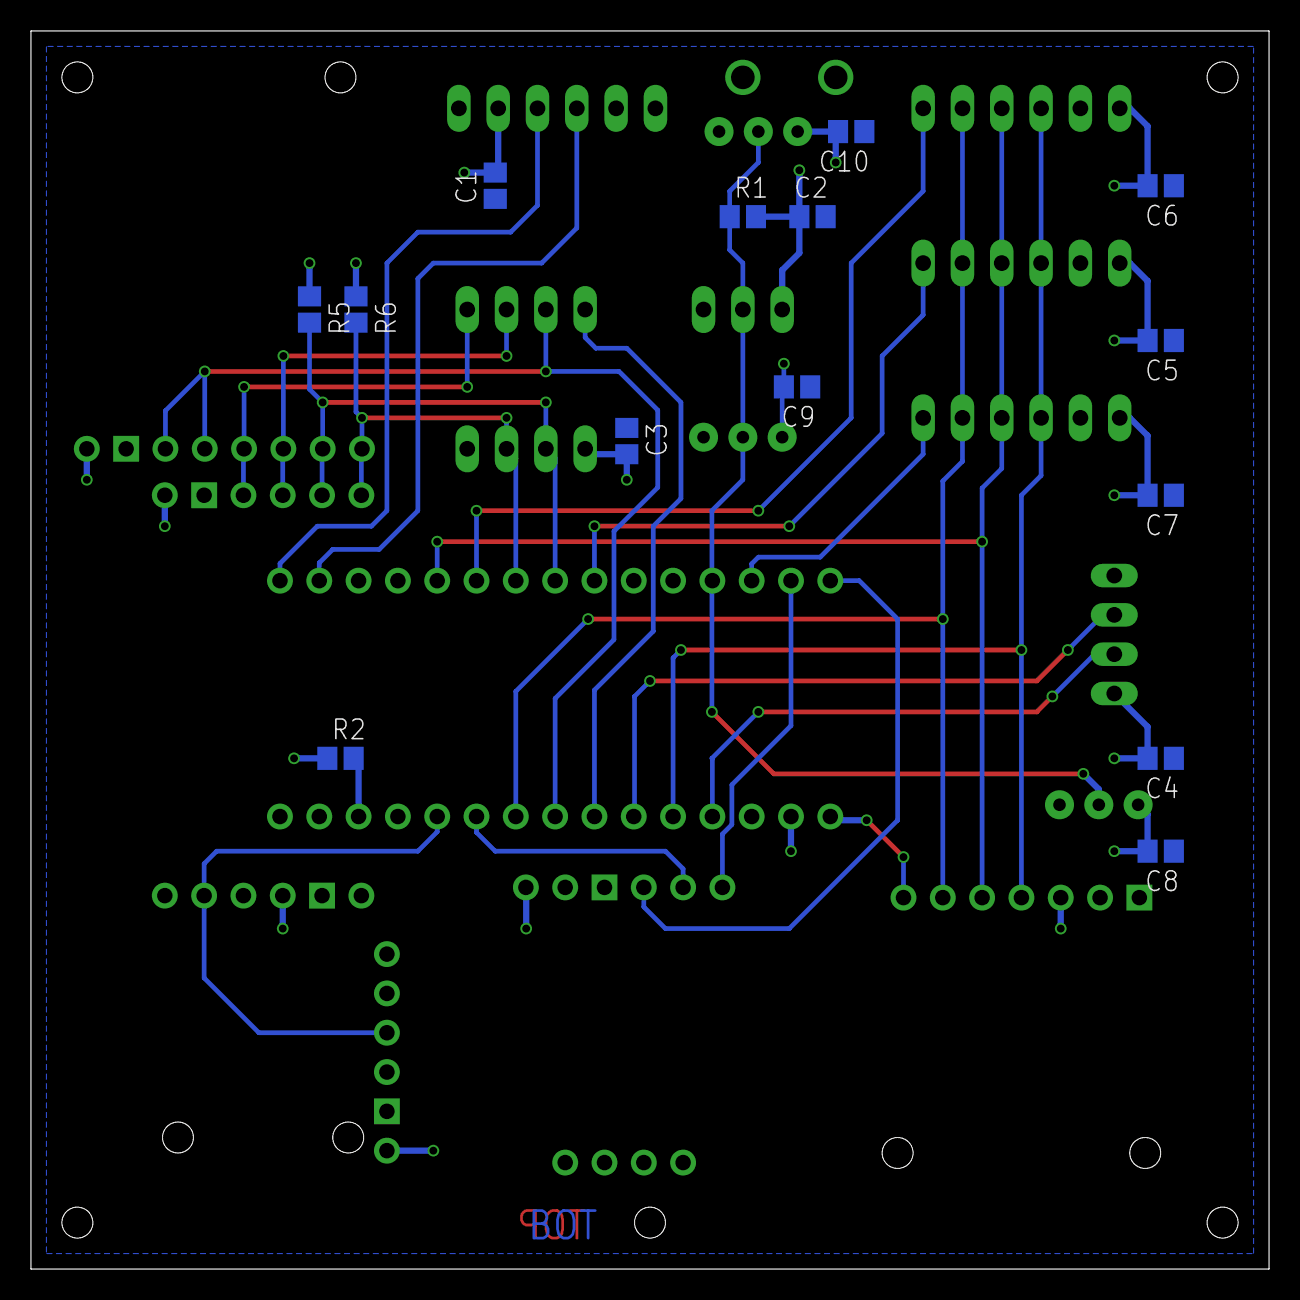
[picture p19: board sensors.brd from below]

Board: 2 copper layers, 80.0 x 80.0 mm, 32 parts (14 on the bottom side), 25 nets.

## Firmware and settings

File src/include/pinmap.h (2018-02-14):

#pragma once

#define CDH_RX      D0
#define CDH_TX      D1
#define SPI_MOSI    D2
#define SPI_CS_ENV0 D3
#define GPS_SDA     D4
#define GPS_SCL     D5
#define SPI_CS_ADCS D6
#define TEMP_OW     D9
#define SPI_CS_SUN  D10
#define IMU_RST     D11
#define IMU_SDA     D12
#define SPI_CS_ENV1 D13
#define SUN_TX      A0
#define SPI_SCK     A1
#define SUN_RX      A2
#define DBG_TX      A3
#define DBG_RX      A4
#define SPI_MISO    A5
#define IMU_SCL     A6
#define LOG_UART    A7

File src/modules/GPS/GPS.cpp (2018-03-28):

/*
 * GPS.cpp
 *
 *  Created on: Jan 21, 2018
 *      Author: tkale
 */

#include <GPS/GPS.hpp>

bool GPS::setup() {
    i2c->frequency(400000);
    set_update_rate(1000); // 2000 doesnot work.

    // Write the config message and wait 100 ms to allow for configuration.
    // #TODO: Parse the UBX-ACK-ACK to really verify that its acknowledged.
    for(int i=0; i < 3; i++) {
        i2c->write(M8_ADDRESS, HA_MODE_CFG, sizeof(HA_MODE_CFG), false);
        Thread::wait(200);
    }

    return true;
}

void GPS::update() {
    if(t_flag) {
        t_flag = false;
        //uint16_t len = getDataLength();
        processBuffer();
    } else {
        last_data = 0;
    }
    getNextChunk(0);
}

void GPS::processBuffer() {

    char *sentence = strtok(data,NMEA_DELIM);
    while(sentence != NULL) {

        // 0xFF is the default value returned when no more
        // data is present.
        if(sentence[0] == 0xFF) break;

        logger->lock();
        logger->puts("RAWGPS ");
        logger->puts(sentence);
        logger->puts("\r\n");
        logger->unlock();

        // Parse the scentence.
        switch(minmea_sentence_id(sentence,false)) {
        case MINMEA_SENTENCE_GLL:
            minmea_parse_gll(&gll, sentence);
            break;
        case MINMEA_SENTENCE_RMC:
            minmea_parse_rmc(&rmc, sentence);
            break;
        case MINMEA_SENTENCE_VTG:
            minmea_parse_vtg(&vtg, sentence);
            break;
        case MINMEA_SENTENCE_GGA:
            minmea_parse_gga(&gga, sentence);
            break;
        default:
            // #TODO: Parse more scentence types here.
            break;
        }
        sentence = strtok(NULL, NMEA_DELIM);
    }


    if(gga.fix_quality != 0){
        gpsData.lat = minmea_tocoord(&gga.latitude);
        gpsData.lon = minmea_tocoord(&gga.longitude);
        gpsData.altitude = minmea_tofloat(&gga.altitude);
        gpsData.trueTrack = minmea_tofloat(&vtg.true_track_degrees);
        gpsData.groundSpeed = minmea_tofloat(&vtg.speed_kph);
        last_data = storage->get_ts();
    } else {
        last_data = 0;
    }

    timespec ts;
    if(!minmea_gettime(&ts, &rmc.date, &gga.time)) {
        gpsData.timestamp = ts.tv_sec;
    }

    storage->lock();
    storage->data->gps = gpsData;
    storage->unlock();
}

void GPS::getNextChunk(uint16_t len) {
    // XXX: The read address of M8_DATA works, but I dont know why!.
    //      Changing it still works.
    //      It seems that the write is being ignored. So writing nothing works
    //      because the I2C register starts at 0xFF by default.
    i2c->transfer(M8_ADDRESS, NULL, 0, (char*)data, BUF_LEN, event_callback_t(this, &GPS::callback), I2C_EVENT_ALL);
}

void GPS::readFromRegister(char device, char reg, char* data, uint32_t len, bool repeated = false) {
    i2c->write(M8_ADDRESS, &reg, repeated);
    i2c->read(M8_ADDRESS, data, len);
}

uint16_t GPS::getDataLength() {
    char len[2];
    readFromRegister(M8_ADDRESS, M8_DATALEN, len, 2, false);

    uint16_t len16 = (((uint16_t)len[0] << 8) | (uint16_t)len[1]);
    //printf("Len:%d\r\n",len16);
    return len16;
}

void GPS::callback(int event) {
    switch(event) {
    case I2C_EVENT_TRANSFER_COMPLETE:
        t_flag = true;
        break;
    default:
        t_flag = false;
    }


}

void GPS::print() {
    // Only print valid data
    if (!last_data) {
        return;
    }

    logger->lock();
    logger->printf("%s T=%lu,"
                   "LAT=%.6f,LON=%.6f,ALT=%.4f,"
                   "TIME=%u,SPEED=%.4f,TRUETRK=%.4f"
                   "\r\n",
                   _name, last_data,
                   gpsData.lat, gpsData.lon, gpsData.altitude,
                   gpsData.timestamp, gpsData.groundSpeed, gpsData.trueTrack);
    logger->unlock();
}

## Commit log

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2017-12-16 Change to pass by reference to avoid pointer derefenrencing.
    Also change the constuctor to an initializer list for cleaner code.
    [MPC320X.cpp]
2017-12-17 Switch to C++17 and C11
    Disable strict-aliasing and sized-deallocation to get rid of compiler
    warnings for mbed-os.
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2018-01-15 Add CDH data request handling.
    Currently responds with a dummy packets with the opcode mirrorred in
    the status field.
2018-01-15 Attempt to add support for multiple commands at the same time.
    This is not working yet. For some reason, the rxCallback is fired
    only twice.
    [CDHUart.cpp]
2018-01-15 Update modeserial library to my repo.
    Added support for our Nucleo board. This allows for seamless setup
    of the projects for new members.
2018-01-15 Remove unnecessary command buffer.
    Also change `rxGetLastChar()` to `getc` to prevent a buffer overflow.
    [CDHUart.cpp]
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2018-01-29 Improve logging output
    - Prepend logs with sensor name BNO055
    - Make output format consistent
    - Remove commented code
2018-01-29 Make output consistent to official output
    Commented code tends to stay, or might be reused in the Sensors::log() function, so lets make it pretty.
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2018-01-30 Add DS18B20 Support.
    Currently just supports a simple scan on the bus and prints out the
    temperatures of all the devices present on the bus.
2018-01-30 Change to a threaded architecture for Temperature sensor updates.
    Also updates the global sensor datastructure so that CDH now recieves
    real temperature data.
    A micro reset is required to recognize any new temperature sensors.
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2018-01-31 Add resetting sensor if selected values are zero, correct RESET pin
2018-02-01 Add checking for zeroes and counting resets and printing it
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2018-02-01 Use right printf argument for unsigned ints, shorten output by renaming keys
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2018-02-08 Reduce the time the onewire sensor locks the shared data struct
    Each onewire read takes ~12ms, writing to the shared data struct after
    all sensors have been read reduces the total time the data struct is
    locked to ~15us.
2018-02-14 Implement review feedback
    - Rename bme680 chip select pin
    - Pass BNO055 reset pin from sensors class
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2018-02-15 Create eagle project
    [mainpanel.sch]
2018-02-15 Add Nucleo board
    [mainpanel.sch]
2018-02-15 Add BNO055 and connections
    [mainpanel.sch]
2018-02-15 Add brd
    [mainpanel.brd]
2018-02-15 Add components to sch
    [mainpanel.brd, mainpanel.sch]
2018-02-15 Place components on brd
    [mainpanel.brd]
2018-02-15 Add connectors
    [mainpanel.brd, mainpanel.sch]
2018-02-15 Add more connectors
    [mainpanel.brd, mainpanel.sch]
2018-02-15 Add values for parts
    [mainpanel.brd, mainpanel.sch]
2018-02-15 Move parts on sch
    [mainpanel.brd, mainpanel.sch]
2018-02-15 Add DS18B20 sensors
    [mainpanel.brd, mainpanel.sch]
2018-02-15 Set rst pin to vcc
    [mainpanel.brd, mainpanel.sch]
2018-02-15 Add individual connectors for all external boards
    [mainpanel.brd, mainpanel.sch]
2018-02-15 Update frame
    [mainpanel.sch]
2018-02-15 Move components
    [mainpanel.sch]
2018-02-15 Move components and add 3rd DS18B20
    [mainpanel.brd, mainpanel.sch]
2018-02-15 Move stuff
    [mainpanel.brd, mainpanel.sch]
2018-02-15 Use rcl lib for resistors
    [mainpanel.brd, mainpanel.sch]
2018-02-15 Use 0.1uF caps on all vcc/gnd lines
    [mainpanel.brd, mainpanel.sch]
2018-02-15 Disconnect pin 6 to cdh
    [mainpanel.brd, mainpanel.sch]
2018-02-15 Add multi-cb dru
    [mainpanel.brd]
2018-02-15 Add net class
    [mainpanel.brd, mainpanel.sch]
2018-02-15 Move caps/res to bot layer
    [mainpanel.brd]
2018-02-15 Set top plane to vcc
    [mainpanel.brd]
2018-02-15 Connect vcc pins to top plane
    [mainpanel.brd]
2018-02-15 Add trestrict for autorouter
    [mainpanel.brd]
2018-02-15 Connect board components
    [mainpanel.brd]
2018-02-15 Remove trestrict again
    [mainpanel.brd]
2018-02-15 Update lib
    [mainpanel.brd, mainpanel.sch]
2018-02-15 Ripup all signals
    [mainpanel.brd]
2018-02-15 Implement feedback
    - BNO055 RST line
    - Del BNO055 pullups
    - 3 pin hdr for OW sensors
    [mainpanel.brd, mainpanel.sch]
2018-02-15 Add BME680 onboard
    [mainpanel.brd, mainpanel.sch]
2018-02-15 Add mounting holes
    [mainpanel.brd]
2018-02-15 Add power connections
    [mainpanel.brd, mainpanel.sch]
2018-02-15 Update spi connectors
    [mainpanel.brd, mainpanel.sch]
2018-02-15 Route board
    [mainpanel.brd]
2018-02-15 Improve layout
    [mainpanel.brd, mainpanel.sch]
2018-02-15 Add info to silkscreen
    [mainpanel.brd]
2018-02-15 Remove groundplane around gps
    [mainpanel.brd]
2018-02-15 Switch to multi-cb dru again
    [mainpanel.brd]
2018-02-15 Update components from lib
    [mainpanel.brd, mainpanel.sch]
2018-02-15 Update groundplane dimensions and change caps
    [mainpanel.brd, mainpanel.sch]
2018-02-15 Add caps for onewire sensors
    [mainpanel.brd, mainpanel.sch]
2018-02-15 Move some wires
    [mainpanel.brd]
2018-02-15 Add trestrict around vcc pads for connection through cap
    [mainpanel.brd]
2018-02-15 Move and rename hw files
    [sensors.brd, sensors.sch]
2018-02-15 Update pin names to match sw
    [sensors.brd, sensors.sch]
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2018-03-07 Update location only if we have a valid fix.
    [GPS.cpp]
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2018-03-07 Print using the logger class to try to avoid print collissions.
    [GPS.cpp]
2018-03-07 Parse valid time when fix is not valid yet.
    [GPS.cpp]
2018-03-07 Add note for the hack that works for reading GPS.
    Also attempt to add files to mbedignore and fail.
    [GPS.cpp]
2018-03-07 Add a mutex to the serial class to prevent printf's getting Garbled.
    Also sets a default baudrate for the new serial class.
    Fix sentence name typo.
    [GPS.cpp]
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2018-03-12 Fix system stats print
    [GPS.cpp]
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2018-03-14 Lock serial when warning about failed Sidepanel communication
    [Sidepanel.cpp]
2018-03-14 Ignore -1000 temperatures as this indicates CRC failures.
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2018-03-20 Merge the two IMU reset types into one
    Before it was split into resets where only temperatures show invalid value (104 degrees) and where all sensors show zeroes. Now this is combined into one counter, but it can still be determined which one has which value by looking at half the byte for each counter,.
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2018-03-22 Fix debug print formatting and minor whitespace cleanup
    [GPS.cpp]
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2018-03-23 Correct the GPS print statement.
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2018-03-24 Fix number of temp sensors to 7; Change datatype to int.
    They should be interpreted as temp/100.
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2018-03-24 Sort GPS print and add missing separator
    [GPS.cpp]
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2018-03-25 Correctly indicate GPS status to CDH
    [GPS.cpp]
2018-03-28 Add retries and I2C error handling for GPS.
    [GPS.cpp]
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2018-03-30 Fix printf format for temperature sensor data
    [moveon-sen-parser.cpp]
2018-03-30 Fix negative temperature printf formatting
2018-04-03 Remove unneeded code
    - Remove commented code that copies unused variables
    - Remove checking undefined variable if it is zero for resetting sensor
    - Remove commented code that could print unused variables
    - Comment unused data structs so that compiler throws error if they are still used
2018-04-03 Fix printing orientation.z twice instead of both x and z
    Introduced in 5b8e29963fdf375c05e7acc01db61e034eac9b3b
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2018-04-04 Fix printf format
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2018-05-26 Add HM-11 module as alternative to OpenLog
    [sensors.brd, sensors.sch]
2018-05-26 Add GPS chip with external antenna
    [sensors.brd, sensors.sch]
2018-05-26 Connect external GPS chip on board
    [sensors.brd, sensors.sch]
2018-05-26 Update component names
    [sensors.brd, sensors.sch]
2018-05-26 Move debug connector
    [sensors.brd]
2018-05-26 Move external GPS chip
    [sensors.brd]
2018-05-26 Add I2C connector
    [sensors.brd, sensors.sch]
2018-05-27 Reroute I2C connections
    [sensors.brd]
2018-05-27 Change dru and fix top/bot label width
    [sensors.brd]
2018-05-27 Add cap for I2C connector
    [sensors.brd, sensors.sch]
2018-05-27 Add some labels
    [sensors.brd]

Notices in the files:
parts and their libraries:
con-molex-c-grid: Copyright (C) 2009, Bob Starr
